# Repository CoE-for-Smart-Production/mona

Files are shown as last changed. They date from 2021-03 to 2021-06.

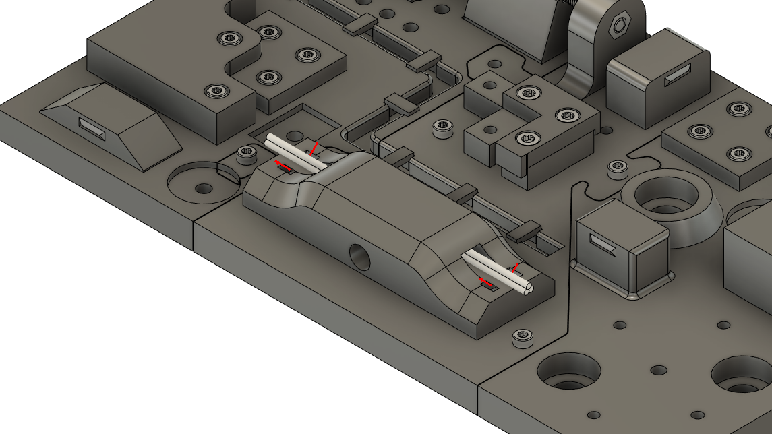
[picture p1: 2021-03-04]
Images/Workinstruction/AS11_2.png

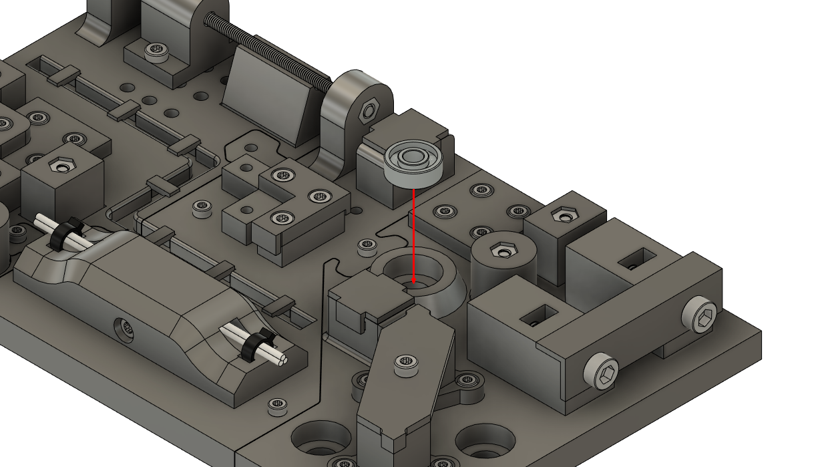
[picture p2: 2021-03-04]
Images/Workinstruction/AS18_1.png

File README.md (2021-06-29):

<h1>MONA</h1>
<h3>a 3d MOdel for the evaluation of maNual Assembly tasks</h3>

This repository contains all files and information to use MONA in your own research facility.
All provided .md files can be viewed directly in the browser.

<h3>Checklists</h3>

Contains checklists (in English and German) for all needed materials and parts for the assembly. 

<h3>Work Instruction</h3>

Contains work instructions (in English and German) for the full assembly of MONA.

<h3>Images</h3>

All images used in the the work instruction as well as images for pre-assembly.

<h3>Models</h3>

Contains all individual parts for 3D printing (.stl file format) and the whole MONA for use in digital work instructions (.obj and .fbx file format).

<h3>License</h3>

When using this abstract assembly object for your evaluations, cite this paper: 

Blattner, Jakob and Wolfartsberger, Josef and Lindorfer, René and Froschauer, Roman and Pimminger, Sebastian and Kurschl, Werner, A Standardized Approach to Evaluate Assistive Systems for Manual Assembly Tasks in Industry (June 2, 2021). Proceedings of the Conference on Learning Factories (CLF) 2021, Available at SSRN: https://ssrn.com/abstract=3858632 or http://dx.doi.org/10.2139/ssrn.3858632

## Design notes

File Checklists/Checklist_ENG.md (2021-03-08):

# Checkliste MONA

## Required tools (depend on screw heads)

-   Allen key size 2.5

-   Allen key size 3

-   Allen key size 5

-   Cable pliers

## Required workpieces

### Not 3D printed

-   Screws:

    -   11x M3x12mm

    -   3x M3x16mm

    -   3x M3x20mm

    -   2x M4x14mm

    -   5x M4x20mm

    -   1x M4x30mm

    -   2x M6x25mm (up to 42mm)

-   Nuts

    -   17x M3

    -   9x M4

    -   2x M6

-   M4x120mm threaded rod

-   2x 2,5mm cable ties **(per test person)**

-   1x 20cm long cable (max. diameter: 4mm)

-   1x 10cm long cable loom (max. diameter: 4mm)

-   1x 606zz ball bearing

### 3D printed

-   BP_1, BP_2, BP_3 (pre-assembled to BP_123 - requires 5x M3x10mm
    screws and 5x M3 nuts)

-   1x TL_M4_Hole

-   1x TL_MR_Rest

-   1x TR_Screw_Block

-   1x TR_M6_Corner

-   7x Cable_Clip

-   1x TM_Attachement

-   1x BL_Block

-   1x BL_Block_Top

-   2x BR_Column

-   1x BR_Connector

-   2x M4_Attachment_Cylinder

-   2x M4_Attachment_Square

-   3x Top_Clip

## Assembly

Before printing, make sure to test the [3D printers
accuracy](https://teachingtechyt.github.io/calibration.html/#flow), as
this ensures an easier assembly. After printing, redrill all screw holes
in the printed object to ensure enough space for the screws to go
through.

Now, the base station needs to be assembled with the help of the
*pre_evaluation_assembly.png* image in the downloaded image folder and
five M3 nuts and screws.

After that, use said image to melt M3 and M4 nuts for the assembly
process into the underside of the base plate with the help of a
soldering iron. Finally, use the paper-based work instruction or create
a new work instruction using the provided images and 3D models to show a
modified assembly process.

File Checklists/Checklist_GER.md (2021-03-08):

# Checkliste MONA

## Benötigtes Werkzeug (von den Schraubköpfen abhängig):

-   Inbusschlüssel Größe 2.5

-   Inbusschlüssel Größe 3

-   Inbusschlüssel Größe 5

-   Kabelzange

## Benötigte Werkstücke:

### Nicht 3D gedruckt

-   Schrauben:

    -   11x M3x12mm

    -   3x M3x16mm

    -   3x M3x20mm

    -   2x M4x14mm

    -   5x M4x20mm

    -   1x M4x30mm

    -   2x M6x25mm (bis max. 42mm)

-   Muttern

    -   17x M3

    -   9x M4

    -   2x M6

-   M4x120mm Gewindestange

-   2x 2,5mm breite Kabelbinder **(pro Proband)**

-   1x 20cm langes Kabel (max. Durchmesser: 4mm)

-   1x 10cm langer Kabelstrang (max. Durchmesser: 4mm)

-   1x 606zz Kugellager

### 3D gedruckt

-   BP_1, BP_2, BP_3 (vormontiert zu BP_123 -- benötigt 5x M3x10mm
    Schrauben und 5x M3 Muttern)

-   7x Cable_Clips

-   3x Top_Clips

-   2x M4_Attachment_Cylinder

-   2x M4_Attachment_Square

-   2x BR_Column

-   1x TR_Screw_Block

-   1x TR_M6_Corner

-   1x TM_Attachement

-   1x TL_M4_Hole

-   1x TL_MR_Rest

-   1x BR_Connector

-   1x BL_Block_Top

-   1x BL_Block

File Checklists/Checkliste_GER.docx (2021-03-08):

# Checkliste MONA

## Benötigtes Werkzeug (von den Schraubköpfen abhängig):

- Inbusschlüssel Größe 2.5
- Inbusschlüssel Größe 3
- Inbusschlüssel Größe 5
- Kabelzange

## Benötigte Werkstücke:

### Nicht 3D gedruckt

- Schrauben:
  - 11x M3x12mm
  - 3x M3x16mm
  - 3x M3x20mm
  - 2x M4x14mm
  - 5x M4x20mm
  - 1x M4x30mm
  - 2x M6x25mm (bis max. 42mm)
- Muttern
  - 17x M3
  - 9x M4
  - 2x M6
- M4x120mm Gewindestange
- 2x 2,5mm breite Kabelbinder (pro Proband)
- 1x 20cm langes Kabel (max. Durchmesser: 4mm)
- 1x 10cm langer Kabelstrang (max. Durchmesser: 4mm)
- 1x 606zz Kugellager

### 3D gedruckt

- BP_1, BP_2, BP_3 (vormontiert zu BP_123 – benötigt 5x M3x10mm Schrauben und 5x M3 Muttern)
- 7x Cable_Clips
- 3x Top_Clips
- 2x M4_Attachment_Cylinder
- 2x M4_Attachment_Square
- 2x BR_Column
- 1x TR_Screw_Block
- 1x TR_M6_Corner
- 1x TM_Attachement
- 1x TL_M4_Hole
- 1x TL_MR_Rest
- 1x BR_Connector
- 1x BL_Block_Top
- 1x BL_Block

## Vormontage

Testen Sie vor dem Druck unbedingt die Genauigkeit des 3D-Druckers (https://teachingtechyt.github.io/calibration.html/), da dies eine einfachere Montage gewährleistet. Bohren Sie nach dem Druck alle Schraubenlöcher im gedruckten Objekt nach, um genügend Platz für die Schrauben zu gewährleisten.

Nun muss die Basisstation mit Hilfe des Bildes pre_evaluation_assembly.png im heruntergeladenen Bildordner und fünf M3-Muttern und Schrauben zusammengebaut werden.

Danach verwenden Sie besagtes Bild, um mit Hilfe eines Lötkolbens die M3- und M4-Muttern für den Montagevorgang in die Unterseite der Grundplatte einzuschmelzen. Verwenden Sie abschließend die papierbasierte Arbeitsanweisung oder erstellen Sie eine neue Arbeitsanweisung unter Verwendung der bereitgestellten Bilder und 3D-Modelle, um einen modifizierten Montageprozess zu zeigen.

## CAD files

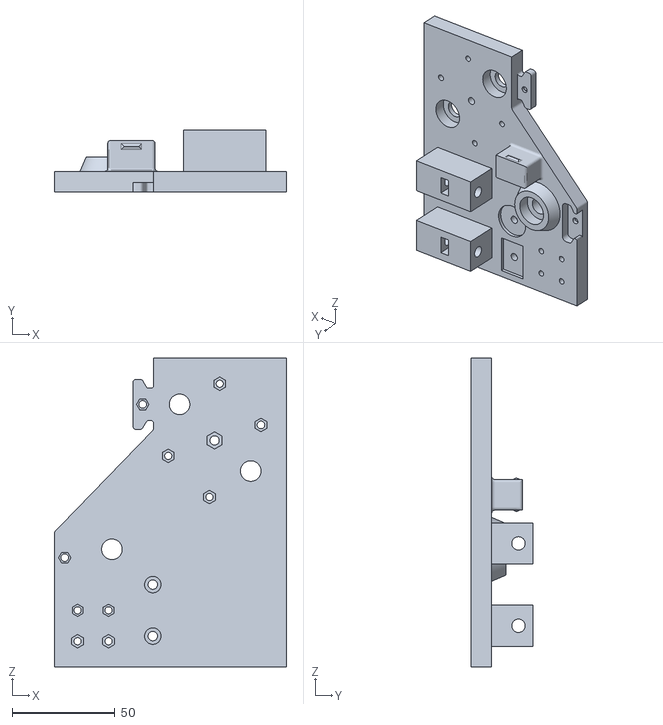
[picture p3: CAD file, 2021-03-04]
Models/STL files/Baseplate_1.stl
112.8 x 30.0 x 150.0

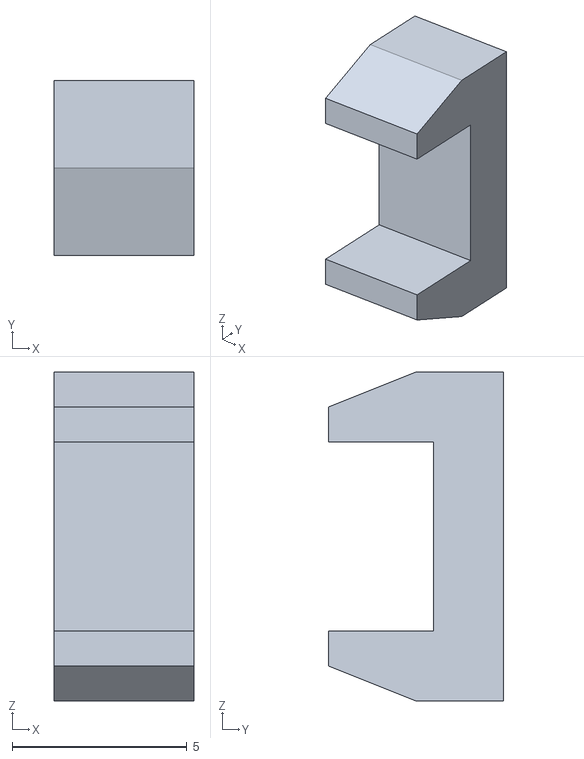
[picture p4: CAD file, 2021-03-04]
Models/STL files/Cable_Clip.stl
4.00 x 5.00 x 9.40

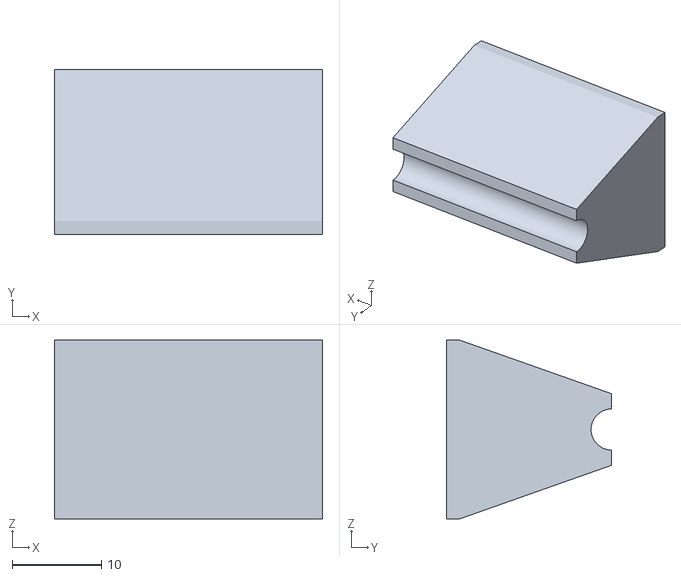
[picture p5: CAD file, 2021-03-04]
Models/STL files/TL_M4_Rest.stl
30.0 x 18.5 x 20.0

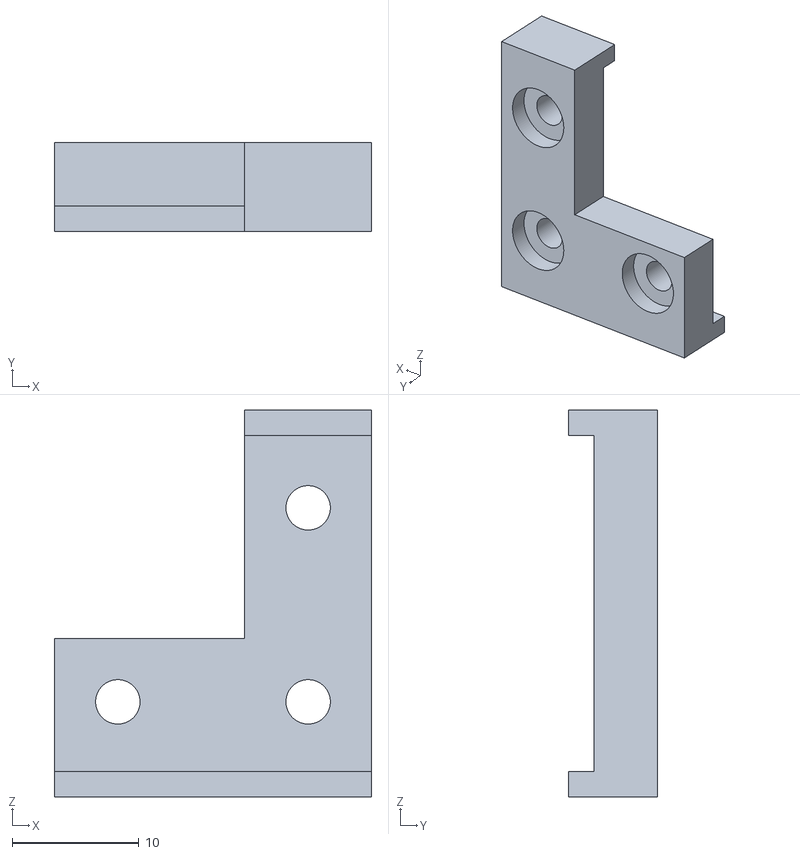
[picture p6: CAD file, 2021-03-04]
Models/STL files/TM_Attachement.stl
25.0 x 7.00 x 30.5

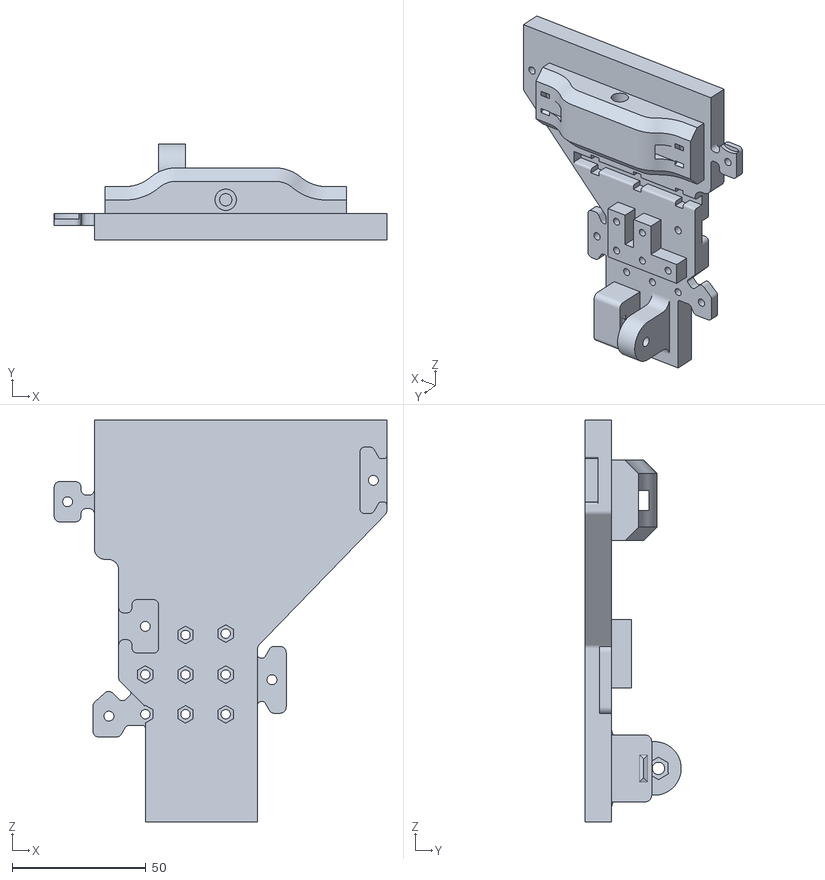
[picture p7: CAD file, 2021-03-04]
Models/STL files/Baseplate_2.stl
124.1 x 36.0 x 150.0

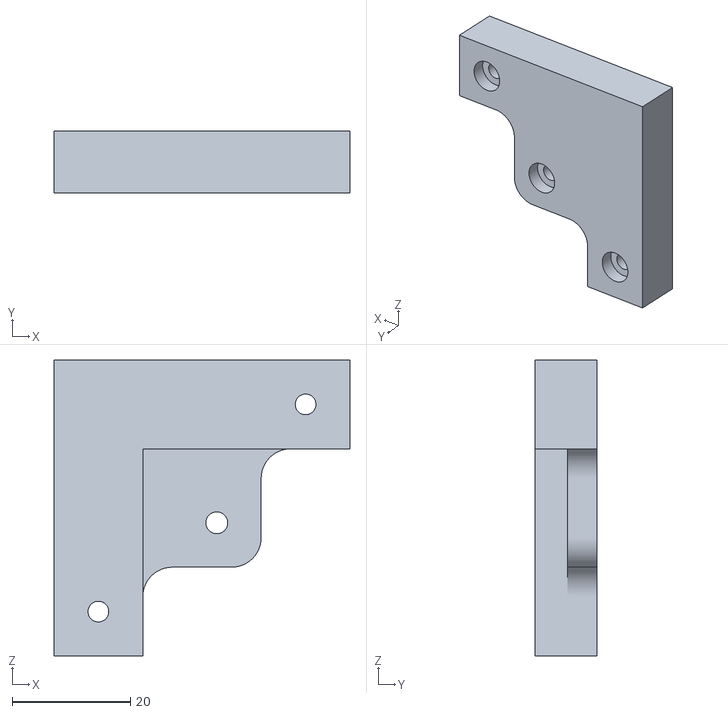
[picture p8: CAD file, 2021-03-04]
Models/STL files/BL_Block_Top.stl
50.0 x 10.5 x 50.0

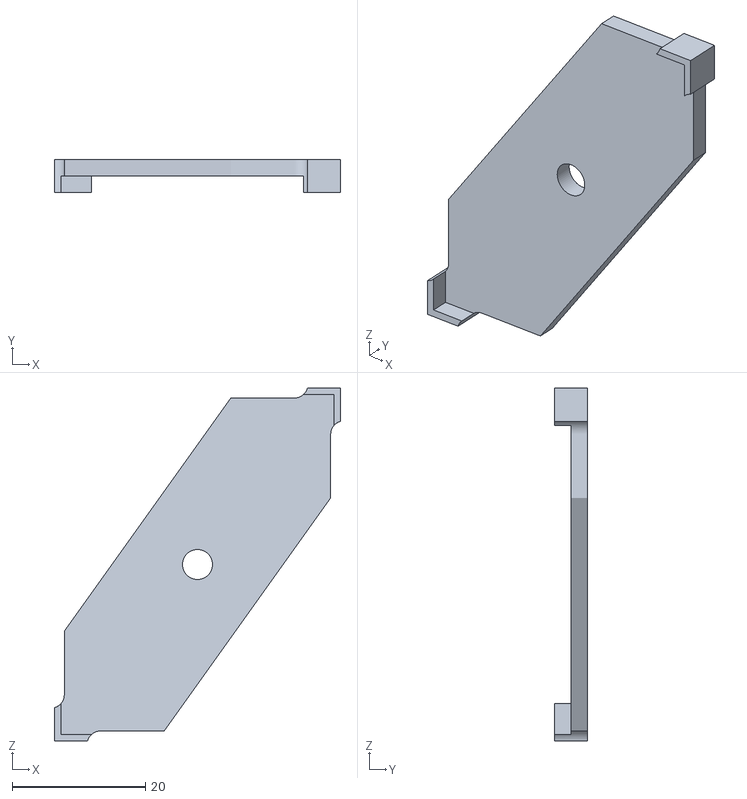
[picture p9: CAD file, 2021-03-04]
Models/STL files/BR_Connector.stl
43.0 x 5.00 x 53.0

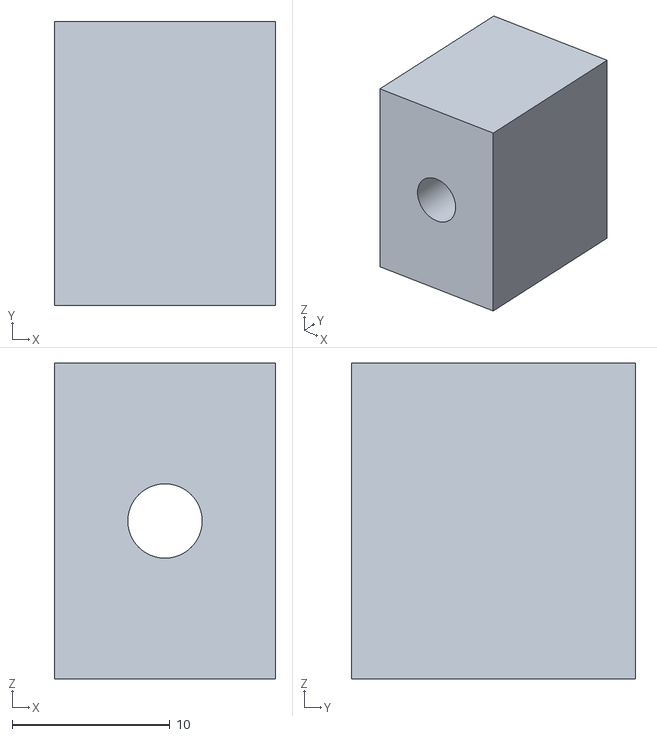
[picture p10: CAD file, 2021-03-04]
Models/STL files/M4_Attachment_Square.stl
14.0 x 18.0 x 20.0

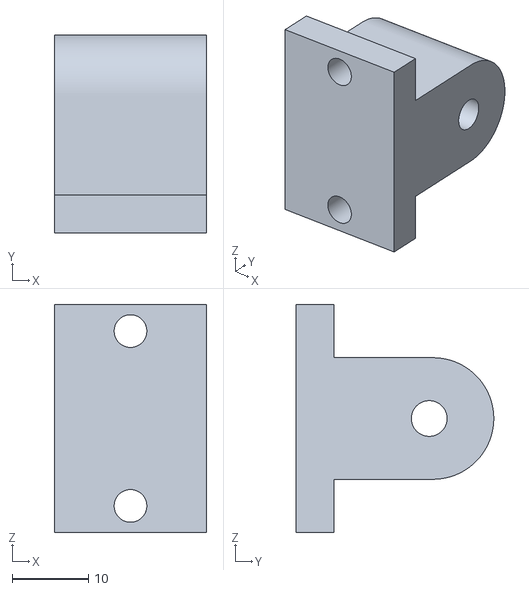
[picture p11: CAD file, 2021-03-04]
Models/STL files/TL_M4_Hole.stl
20.0 x 26.0 x 30.0

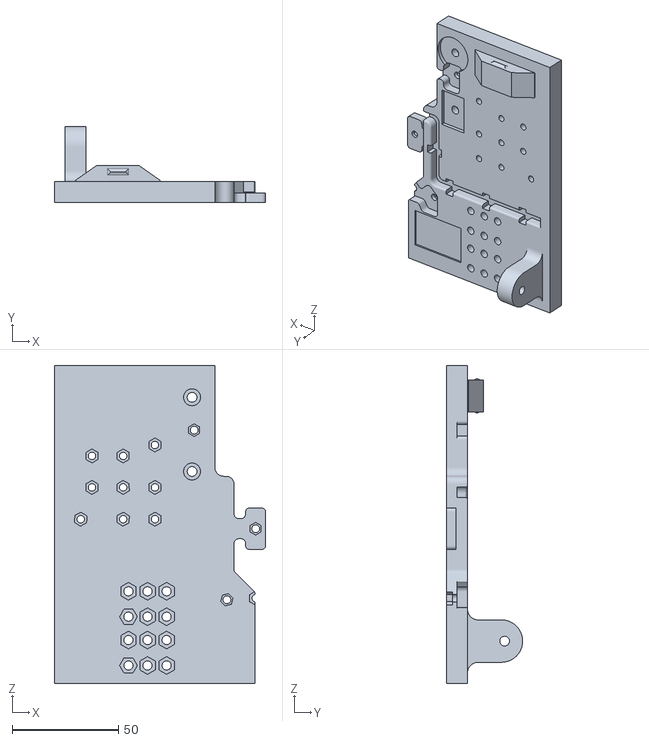
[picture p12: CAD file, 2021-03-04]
Models/STL files/Baseplate_3.stl
99.8 x 36.0 x 150.0

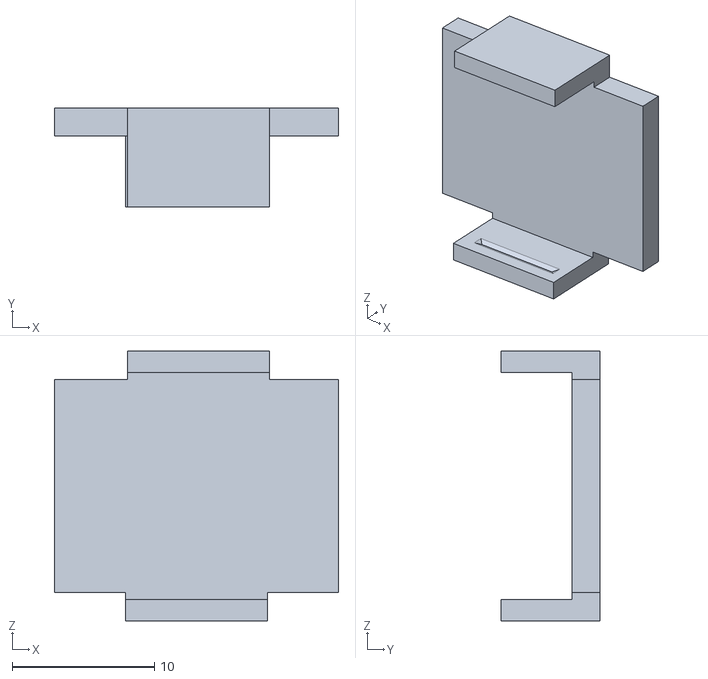
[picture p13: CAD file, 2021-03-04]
Models/STL files/Top_Clip.stl
20.0 x 7.00 x 19.0

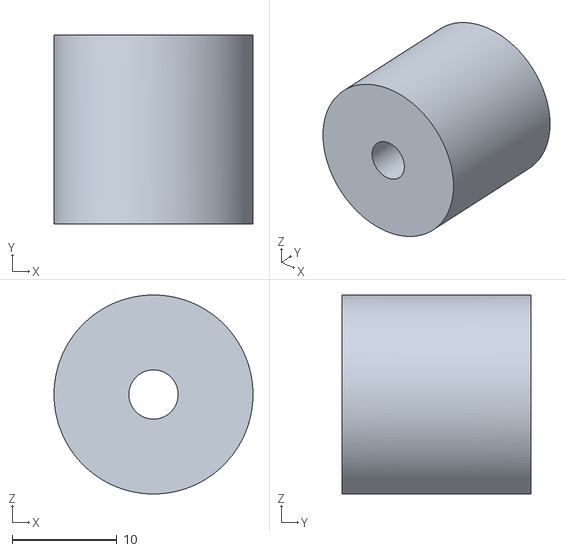
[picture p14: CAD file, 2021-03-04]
Models/STL files/M4_Attachment_Cylinder.stl
19.0 x 18.0 x 19.0

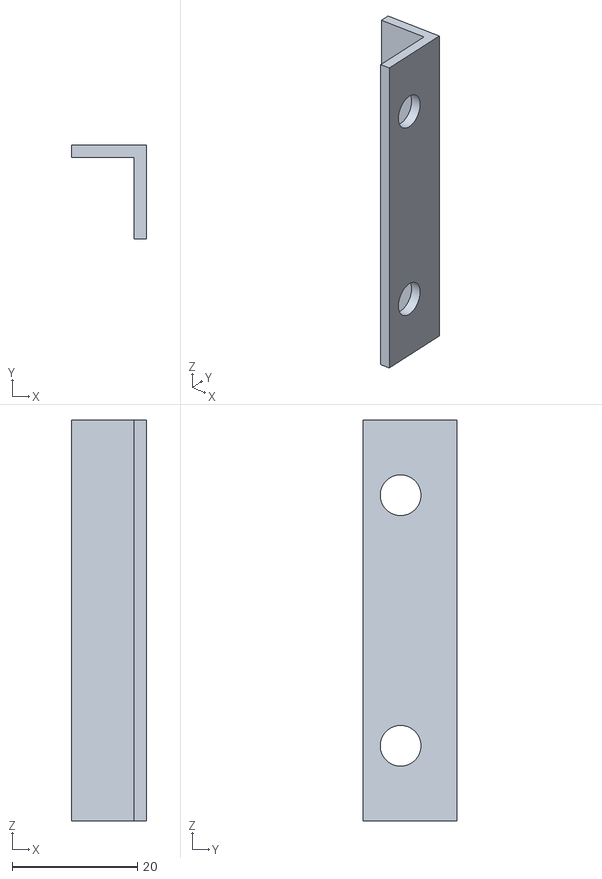
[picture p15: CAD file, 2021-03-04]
Models/STL files/TR_M6_Corner.stl
12.0 x 15.0 x 64.0

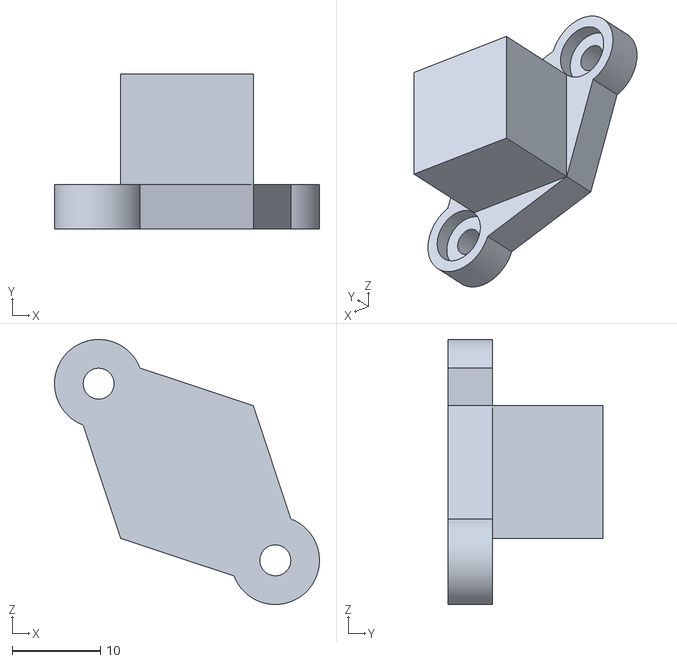
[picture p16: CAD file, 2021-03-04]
Models/STL files/BR_Column.stl
30.0 x 17.5 x 30.0

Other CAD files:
Models/STL files/BL_Block.stl
Models/STL files/TR_Screw_Block.stl

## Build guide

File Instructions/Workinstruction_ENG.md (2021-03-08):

# Work Instruction - MONA

## Work Step 1 -- Place base plate

**Part(s)**: BP_123\
**Tool(s):** -

**Description:** Place the pre-assembled base plate on the table in
front of you.



## Work Step 2 -- Assemble work piece

**Part(s):** TL_M4_Hole, 2x M4x14mm\
**Tool(s):** Allen key 3

**Description:** Place the part in the position shown and fix it to the
base plate with two M4x14mm screws.





## Work Step 3 -- Position of the part

**Part(s):** TL_M4_Rest\
**Tool(s):** -

**Description:** Position the part at the position shown





## Work Step 4 -- Mount threaded rod

**Part(s):** 1x M4 nut, 1x M4 120mm threaded rod \
**Tool(s):** -

**Description:** Position an M4 nut in the position shown and slide the
threaded rod into the position shown. Screw it into the placed M4 nut.







## Work Step 5 -- Assemble work piece

**Part(s):** TR_Screw_Block, 4x M3x12mm \
**Tool(s):**  Allen key 2

**Description:** Place the part in the position shown.\
Fasten the work piece with four M3x12mm screws.





## Work Step 6 - Assemble work piece

**Part(s):** TR_M6_Corner, 2x M6 Nut, 2x M6x25mm Screws\
**Tool(s):** Allen key 5

**Description:** Place the parts on the designated position as shown.\
Insert two M6 nuts into the marked recesses.\
Then fasten the work piece with two M6x25mm screws.









## Work Step 7 -- Lay and fasten cables

**Part(s):** 1x 20cm cable, 7x Cable_Clip\
**Tool(s):** -

**Description:** Place the 20 cm long cable in the marked cable duct.\
Then insert the cable clips into the recesses provided to secure the
cable.







## Work Step 8 -- Assemble work piece

**Part(s):** TM_Attachment, 3x M3x20mm \
**Tool(s):** Allen key 2.5

**Description:** Place the part at the indicated position.\
Attach it with three M3x20mm screws.





## Work Step 9 -- Assemble work piece

**Part(s):** BL_Block, 3x M3x12mm \
**Tool(s):** Allen key 2

**Description:** Place the workpiece at the indicated position.\
Insert and tighten the three shown M3x12mm screws.





## Work Step 10 -- Assemble work piece

**Part(s):** BL_Block_Top, 3x M3x16mm \
**Tool(s):** Allen key 2.5

**Description:** Place the part at the shown position.\
The middle part of it rests on the part from the previous step.\
Secure the part with three M3x16mm screws.





## Work Step 11 -- Lay and secure cable

**Part(s):** 1x 10cm cable loom, 2x 2,5mm cable ties\
**Tool(s):** cable clamp

**Description:** Guide the cable loom through the indicated cable duct.\
Fix the cable loom with two cable ties in the recesses provided.\
Remove the excess end of the cable tie.







## Work Step 12 -- Assemble screw

**Part(s):** 1x M4x20mm, 1x M4 Nut\
**Tool(s):** Allen key 3

**Description:** Assemble the M4 Screw and M4 nut as shown.





## Work Step 13 -- Attach columns

**Part(s):** 2x BR_Column, 4x M3x12mm \
**Tool(s):** Allen key 2

**Description:** Place the two workpieces on the Base plate as shown.\
Mount the two columns with four M3x12mm screws.







## Work Step 14 -- Mount connection piece

**Part(s):** BR_Connector, 1x M4x30mm \
**Tool(s):** Allen key 3

**Description:** Place the part on the two columns and fix it with the
M4 Screw.\
Be careful not to brake the part!





## Work Step 15 -- Assemble work piece

**Part(s):** M4_Attachment_Cylinder, 1x M4x20mm , 1x M4 Nut\
**Tool(s):** Allen key 3

**Description:** Place and attach the tower in the position shown.\
The screw must be tightened from the underside of the base plate.







## Work Step 16 -- Place and assemble parts

**Part(s):** 1x M4_Attachment_Cylinder, 2x M4_Attachment_Square, 3x
M4x20mm, 3x M4 Nut\
**Tool(s):** Allen key 3

**Description:** Repeat the last work step with the three parts shown.









## Work Step 17 -- Mount clips 

**Part(s):** 3x Top_Clip\
**Tool(s):** -

**Description:** Put the clips in the positions illustrated.





## Work Step 18 -- insert ball bearing

**Part(s):** 1x 606zz ball bearing\
**Tool(s):** -

**Description:** Insert the ball bearing into the position shown.





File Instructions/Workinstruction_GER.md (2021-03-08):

# Arbeitsanweisung MONA

## Arbeitsschritt 1 -- Grundplatte auflegen

**Werkstück(e)**: BP_123\
**Werkzeug(e):** -

**Beschreibung:** Legen Sie die vormontierte Grundplatte vor sich auf
den Tisch



## Arbeitsschritt 2 -- Werkstück montieren

**Werkstück(e):** TL_M4_Hole, 2x M4x14mm\
**Werkzeug(e):** Inbusschlüssel 3

**Beschreibung:** Setzen Sie das Werkstück(e) auf die abgebildete
Position und befestigen es mit zwei M4x14mm Schrauben an der
Grundplatte.





## Arbeitsschritt 3 -- Werkstück positionieren

**Werkstück(e):** TL_M4_Rest\
**Werkzeug(e):** -

**Beschreibung:** Positionieren Sie das Werkstück an der gezeigten
Position





## Arbeitsschritt 4 -- Gewindestange montieren

**Werkstück(e):** 1x M4 Mutter, 1x M4 Gewindestange 120mm\
**Werkzeug(e):** -

**Beschreibung:** Positionieren Sie eine M4 Mutter an gezeigter Position
und schieben die Gewindestange in die abgebildete Position. Verschrauben
Sie diese mit der platzierten M4 Mutter.







## Arbeitsschritt 5 -- Werkstück montieren

**Werkstück(e):** TR_Screw_Block, 4x M3x12mm \
**Werkzeug(e):** Inbusschlüssel 2

**Beschreibung:** Setzen Sie das Werkstück auf die abgebildete Position.
Befestigen sie das Werkstück mit vier M3x12mm Schrauben.





## Arbeitsschritt 6 - Werkstück montieren

**Werkstück(e):** TR_M6_Corner, 2x M6 Mutter, 2x M6x25mm Schrauben\
**Werkzeug(e):** Inbusschlüssel 5

**Beschreibung:** Legen Sie das Werkstück wie abgebildet auf die dafür
vorgesehene Position. Stecken Sie zwei M6 Muttern in die markierten
Ausnehmungen. Befestigen Sie anschließend das Werkstück mit zwei M6x25mm
Schrauben.









## Arbeitsschritt 7 -- Kabel legen und befestigen

**Werkstück(e):** 1x 20cm Kabel, 7x Cable_Clip\
**Werkzeug(e):** -

**Beschreibung:** Legen Sie das 20cm lange Kabel in den markierten
Kabelkanal. Danach stecken Sie die Kabelclips in die dafür vorgesehenen
Ausnehmungen um das Kabel zu fixieren







## Arbeitsschritt 8 -- Werkstück montieren

**Werkstück(e):** TM_Attachment, 3x M3x20mm\
**Werkzeug(e):** Inbusschlüssel 2.5

**Beschreibung:** Platzieren Sie das Werkstück an der angezeigten
Position. Befestigen das Werkstück mit drei M3x20mm Schrauben.





## Arbeitsschritt 9 -- Werkstück montieren

**Werkstück(e):** BL_Block, 3x M3x12mm \
**Werkzeug(e):** Inbusschlüssel 2

**Beschreibung:** Platzieren Sie das Werkstück an der angezeigten
Position. Befestigen Sie nun das Werkstück mit drei M3x12mm Schrauben.





## Arbeitsschritt 10 -- Werkstück montieren

**Werkstück(e):** BL_Block_Top, 3x M3x16mm\
**Werkzeug(e):** Inbusschlüssel 2.5

**Beschreibung:** Platzieren Sie das Werkstück an der angezeigten
Position.\
Der mittlere Teil des Werkstücks liegt auf dem Werkstück des vorherigen
Schrittes auf.\
Befestigen Sie das Werkstück mit drei M3x16mm Schrauben.





## Arbeitsschritt 11 -- Kabel legen und fixieren

**Werkstück(e):** 1x 10cm Kabelstrang, 2x 2,5mm Kabelbinder\
**Werkzeug(e):** Kabelzange

**Beschreibung:** Führen Sie den Kabelstrang durch den angezeigten
Kabelkanal.\
Fixieren Sie den Kabelstrang mit zwei Kabelbindern in den dafür
vorgesehenen Ausnehmungen.\
Entfernen Sie das überstehende Ende des Kabelbinders







## Arbeitsschritt 12 -- Schraube befestigen

**Werkstück(e):** 1x M4x20mm, 1x M4 Mutter\
**Werkzeug(e):** Inbusschlüssel 3

**Beschreibung:** Befestigen Sie die M4 Schraube und M4 Mutter wie
abgebildet.





## Arbeitsschritt 13 -- Säulen montieren

**Werkstück(e):** 2x BR_Column, 4x M3x12mm\
**Werkzeug(e):** Inbusschlüssel 2

**Beschreibung:** Platzieren Sie die zwei Werkstücke wie abgebildet auf
der Grundplatte.\
Montieren Sie die zwei Säulen wie angezeigt.







## Arbeitsschritt 14 -- Verbindung befestigen

**Werkstück(e):** BR_Connector, 1x M4x30mm\
**Werkzeug(e):** Inbusschlüssel 3

**Beschreibung:** Platzieren Sie das Werkstück auf den beiden Säulen und
befestigen es mit der M4 Schraube wie abgebildet.\
Achten Sie darauf, dass Sie das Teil nicht brechen!





## Arbeitsschritt 15 -- Werkstück montieren

**Werkstück(e):** M4_Attachment_Cylinder, 1x M4x20mm , 1x M4 Mutter\
**Werkzeug(e):** Inbusschlüssel 3

**Beschreibung:** Platzieren Sie den Turm an der gezeigten Position.
Befestigen Sie diesen anschließend wie abgebildet. Die Schraube muss von
der Unterseite der Grundplatte angezogen werden.







## Arbeitsschritt 16 -- Werkstück platzieren und befestigen

**Werkstück(e):** 1x M4_Attachment_Cylinder, 2x M4_Attachment_Square, 3x
M4x20mm, 3x M4 Mutter\
**Werkzeug(e):** Inbusschlüssel 3

**Beschreibung:** Wiederholen Sie den letzten Arbeitsschritt mit den
drei gezeigten Werkstücken.









## Arbeitsschritt 17 -- Clips befestigen 

**Werkstück(e):** 3x Top_Clip\
**Werkzeug(e):** -

**Beschreibung:** Stecken Sie die Clips auf die gezeigten Positionen.





## Arbeitsschritt 18 -- Kugellager einstecken

**Werkstück(e):** 1x 606zz Kugellager\
**Werkzeug(e):** -

**Beschreibung:** Stecken Sie das Kugellager in die abgebildete Position





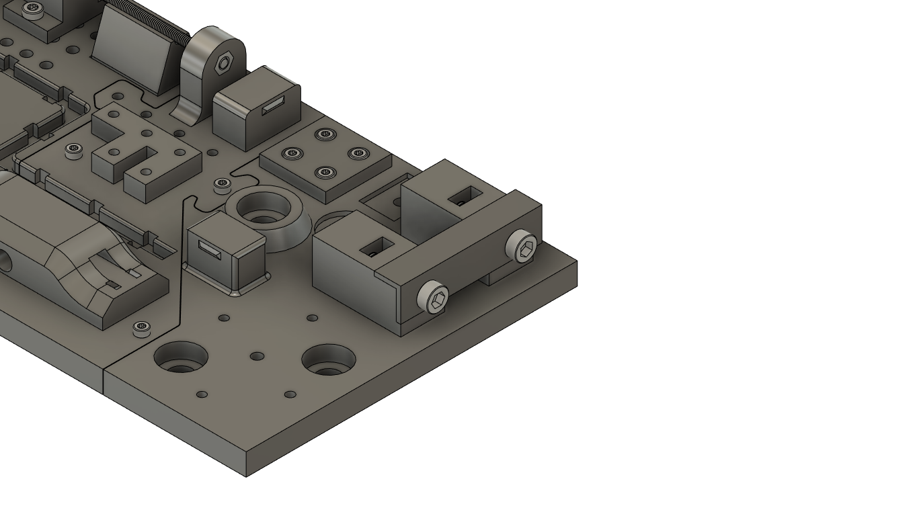
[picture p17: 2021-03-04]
Images/Workinstruction/AS6_4.png

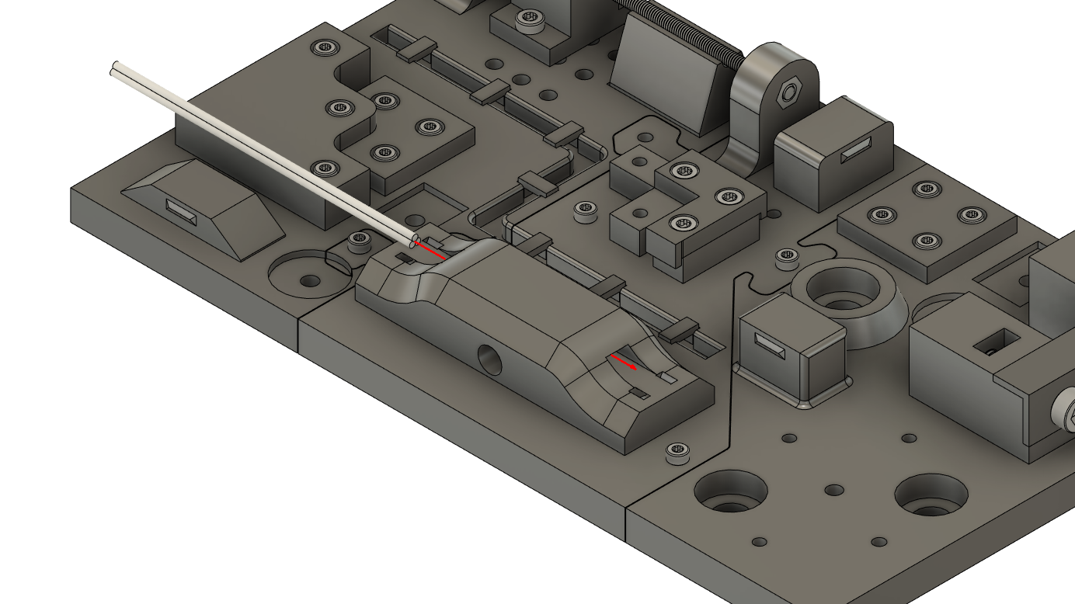
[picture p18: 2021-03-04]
Images/Workinstruction/AS11_1.png

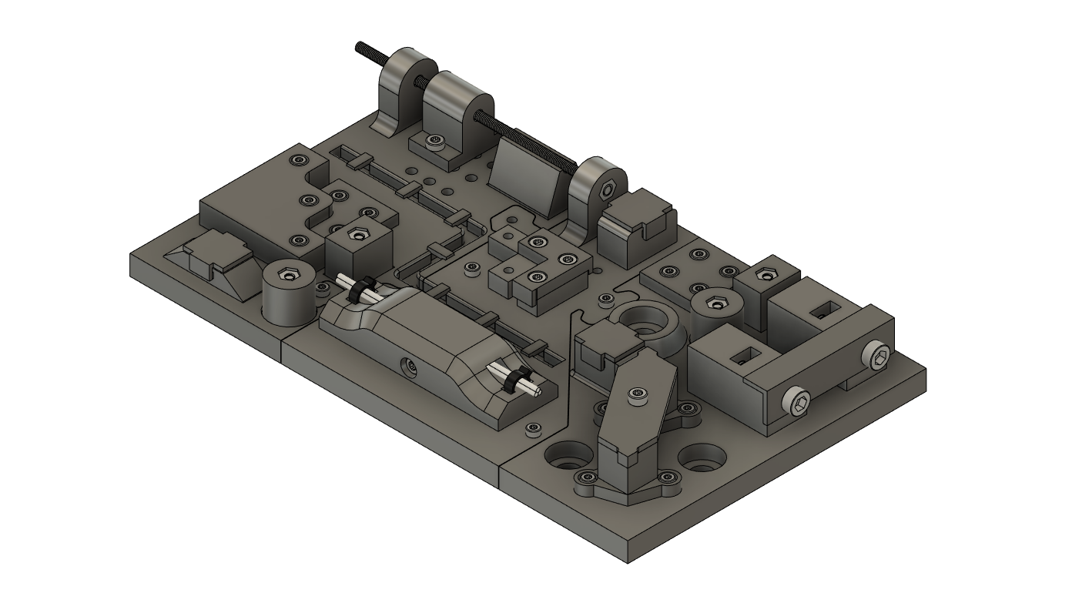
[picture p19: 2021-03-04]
Images/Workinstruction/AS17_2.png

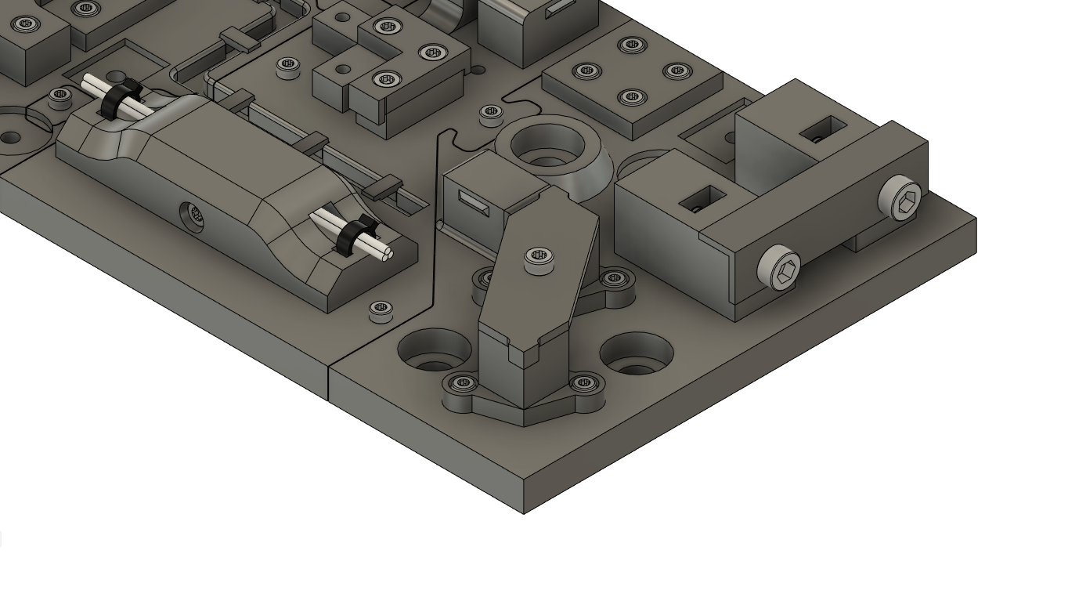
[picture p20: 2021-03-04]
Images/Workinstruction/AS14_2.png
